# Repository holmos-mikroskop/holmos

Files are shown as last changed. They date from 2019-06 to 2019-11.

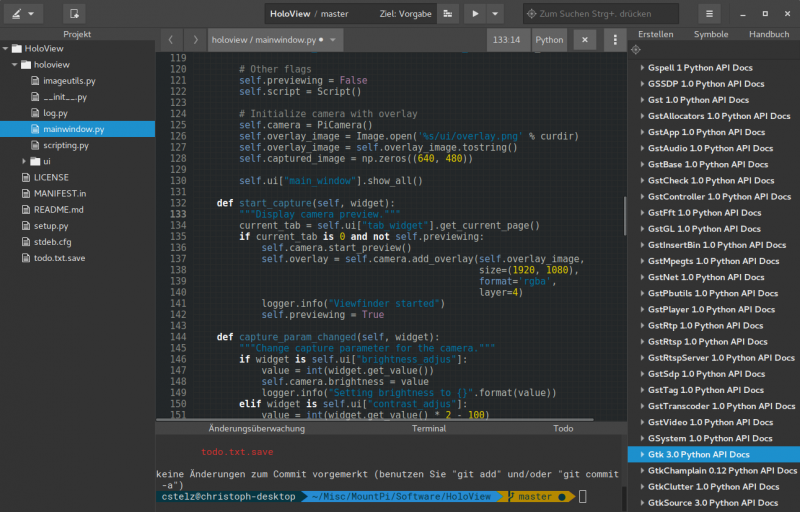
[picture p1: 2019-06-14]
doku-img/gnome-builder.png

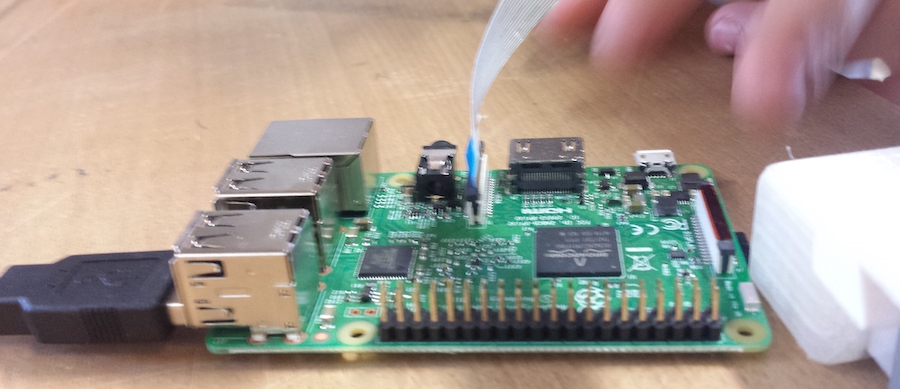
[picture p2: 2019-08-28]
doku-img/kamera-anschliessen-03.jpg

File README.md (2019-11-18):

# Digital-holographisches Mikroskop for OpenScience (HolMOS)

In diesem Projekt wurde von 2016 bis 2019 in Kooperation von Schüler/innen, Lehrern und Mitarbeitern des Fraunhofer-Instituts für Physikalische Messtechnik IPM ein **digital-holographisches Mikroskop entwickelt**, das für Schulen, andere Bildungseinrichtungen und alle Interessierten erschwinglich ist. Die Komponenten sind entweder günstig zu kaufen oder per 3D-Druck herstellbar und können selbst mit Hilfe von Anleitungen zusammen gebaut werden. 

Das Mikroskop ermöglicht 3D-Darstellungen von Objekten, die mit Hilfe des klassischen Lichtmikroskops weniger gut erforschbar sind. 

----

## Kooperationspartner

Das Projekt HolMOS wurde in Kooperation des 
* [Freiburg-Seminars für Mathematik und Naturwissenschaften](https://freiburg-seminar.de/stichwort/holmos/) mit dem     
* [Fraunhofer-Institut für Physikalische Messtechnik IPM](https://www.ipm.fraunhofer.de) in Freiburg durchgeführt. 
    
Gefördert durch das [BMBF](https://www.bmbf.de/).

----

##  Projektdokumentation und Status

Für die Projektdokumentation gibt es zwei parallele Strukturen: 

### (1) Erarbeitet von Schüler/innen

**Umfassende** Darstellung der entwickelten Inhalte und des Codes mit **Anleitungen auf Deutsch**. 

> **STATUS:** 
> * Die Dokumentation ist **abgeschlossen**, 
> * der Code und die Materialien werden **nicht mehr weiterentwickelt**. 

**[Zur Schüler-Dokumentation](https://github.com/holmos-mikroskop/holmos/wiki)**

### (2) Erarbeitet von Mitarbeitern des Fraunhofer IPM

**Knappe** Darstellung der entwickelten Inhalte und des Codes, **Anleitungen auf Englisch**.

> **STATUS:** 
> * Die Dokumentation ist noch **in Bearbeitung**, 
> * Code und Materialien **werden noch weiterentwickelt**. 

**[Zur Fraunhofer-Dokumentation](https://github.com/holmos-ipm)**

----

## Weitere Berichte zum Projekverlauf

Pressemeldungen und Berichte zu Meilensteinen des Projekts sind hier dokumentiert (in umgekehrt chronologischer Reihenfolge): [Projektdokumentation](https://freiburg-seminar.de/stichwort/holmos/)

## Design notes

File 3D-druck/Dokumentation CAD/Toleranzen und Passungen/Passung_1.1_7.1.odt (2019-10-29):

Passungen und Toleranzen

Maßtoleranzen sind die bei der Fertigung zulässigen Differenzen zum idealen Nennmaß. Beispielsweise ist das Ideale Nennmas bei einem Zollstoch 2m und die Maßtolerant beträgt +/- 0.2mm.

Wir benutzen Passungen und Toleranzen um Bauteile beweglich zu machen, da diese individuell einstellbar sein müssen. Wenn wir keine Passungen und Toleranzen benutzen würden, könnte man die Bauteile schwer oder gar nicht bewegen und dadurch kein gutes Bild erzielen.

1.1 / 7.1

Die folgende Passung wurde gewählt, dass die Bauteile perfekt ineinander passen, beweglich und trotzdem stabil sind. Die Bohrung an der Seite des Fußes wurden nicht mit einem Gewinde versehen, da wir M3 Schrauben benutzen, welche das Gewinde selber schneiden. Dies wird bei jedem weiteren Bauteil auch so gemacht.

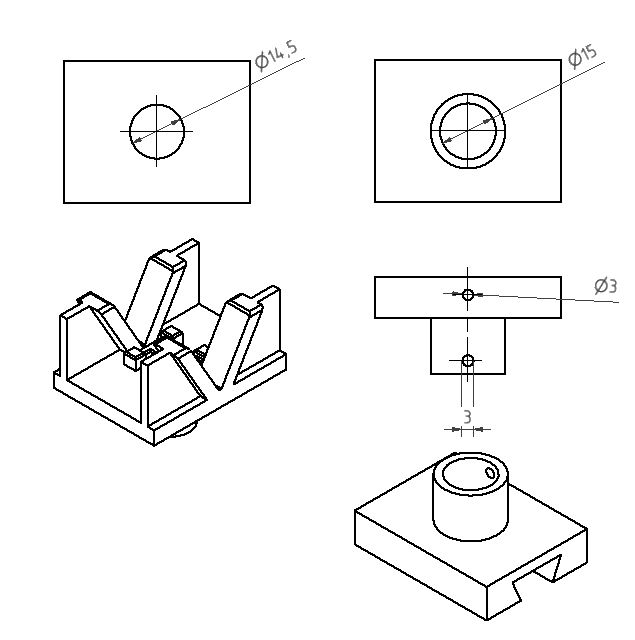
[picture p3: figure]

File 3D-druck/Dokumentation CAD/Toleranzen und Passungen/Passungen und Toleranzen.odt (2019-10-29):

Passungen und Toleranzen

7.1

Die Passungen wurden so Konstruiert das auf jeder Seite ein Millimeter spiel gelassen wurde. Siehe zeichnung.

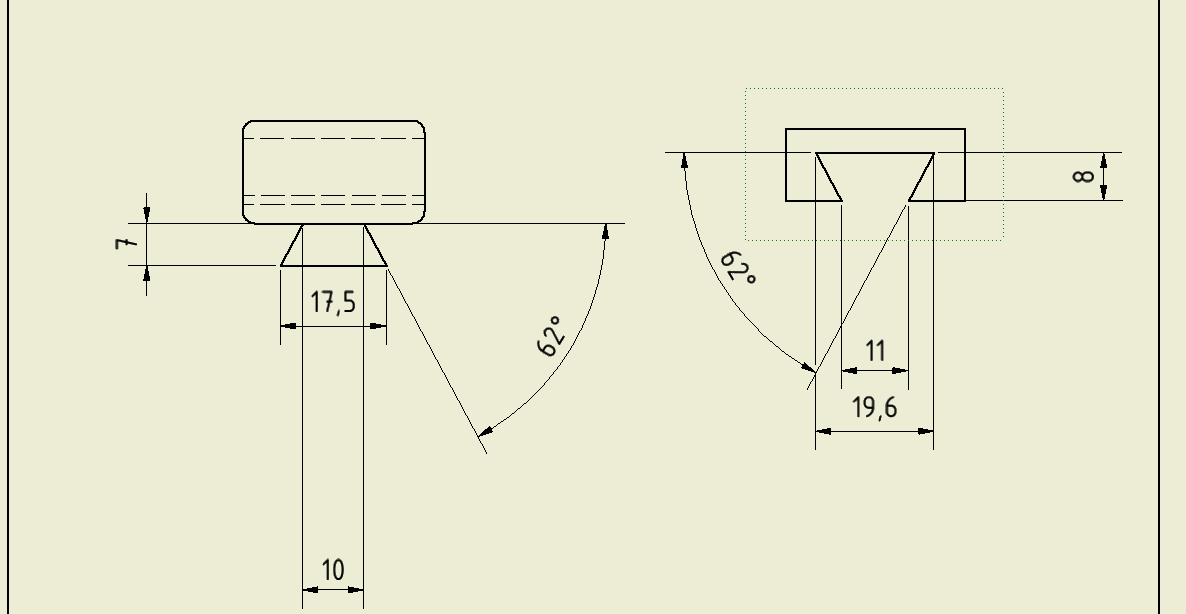
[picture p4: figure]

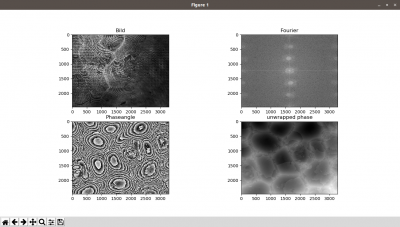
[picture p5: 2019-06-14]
doku-img/einfache-auswertung_004.png

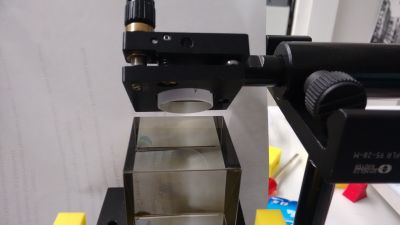
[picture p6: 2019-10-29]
doku-img/justage-laserpointer/justage-05.jpg

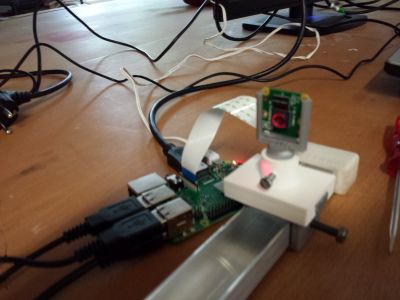
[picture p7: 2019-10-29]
doku-img/justage-laserdiode/justage-laserdiode-10.jpg

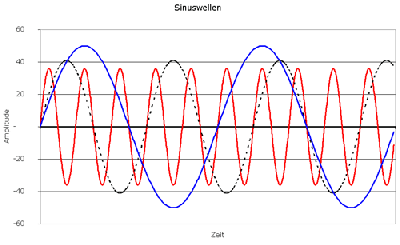
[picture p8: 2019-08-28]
doku-img/interferometer-005.gif

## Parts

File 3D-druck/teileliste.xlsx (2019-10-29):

Normteile | Größe | Länge | Kopf | Menge
1 | M5 | 20 mm | Flügelschraube | 6x | Grundkonstruktion
2 | M3 | 20 mm | Flügelschraube | 5x
3 | M3 | 7 mm | Innensechskant | 4x
4 | M3 | 35 / 40 mm | Innensechskant | 2x | Objektivhalter
5 | M3 |  | Muttern | 2x
6 | M3 | 20 mm | Innensechskant | 4x | Strahlenteiler
7 | M3 |  | Muttern | 4x
8 | M3 | 10 mm | Innensechskant | 4x
9 |  |  | Schiene | 1x
10 |  |  | Kugelschreiberfeder | 4x
11 | Durchmesser 6mm | Gesamtlänge ca. 250mm (6x30mm) | Aluminiumstange | 1x
12 | M5 | 20 mm | Innensechskant | 3x
13 | M5 |  | Muttern | 3x
Druckteile | Pos. Nr. | Name | Menge
 | 1.1 | Laserhalter | 1x | Laser
 | 2.1 | Linse | 1x | Linse
 | 3.1 | Strahlenteiler | 1x | Strahlenteiler
 | 3.2 | Strahlenteiler | 1x | Strahlenteiler
 | 3.3 | Strahlenteiler | 2x | Strahlenteiler
 | 3.4 | Strahlenteiler | 1x | Strahlenteiler
 | 4.1 | Objektträgerhalterung | 1x | Objektträgerhalterung
 | 4.2a | Objektträgerhalterung | 1x | Objektträgerhalterung
 | 4.2b | Objektträgerhalterung | 1x | Objektträgerhalterung
 | 5.1 | Objektivhalterung | 1x | Objektivhalterung
 | 5.2 | Objektivhalterung | 1x | Objektivhalterung
 | 6.1 | Kamera | 1x | Kamera
 | 7.1 | Schlitten mit Rundung verschoben | 3x
 | 7.1 | Schlitten mit Rundung verschoben | 1x
 | 7.1 | Schlitten | 1x
 | 7.2 | Schienenläufer | 5x
 | 7.3 | Schienenläufer STL | 1x
 | 7.4 | Schienenschutz | 2x | Schienenschutz
Optische Komponenten | Name | Beschreibung | Menge | Link
 | Lasermodul: | Laserfuchs Diode OE-QD650-0.4-12(10x22)-ADJ, |  | https://www.laserfuchs.de/de/punktlaser/doe-qd650-0-4-1210x22-adj, Fokus
 | Strahlteiler | 15x15x1mm |  | https://www.lasershop.de/de/strahlteiler-laser-50-50-strahlteilerspiegel.html
 | Spiegel: | Vorderflächen-Glasspiegel 50 mm x 40 mm x 1,3mm |  | https://www.forscherladen.de/vorderflaechen-glasspiegel-50-mm-x-40-mm-x-1-3mm::10-509.VFX.html
 | Linse | Astromedia om-3, plankonvex, +30mm, Durchmesser 16,5mm |  | https://www.forscherladen.de/opti-media-linse-nr.3-brennweite-30-mm::10-304.OML.html

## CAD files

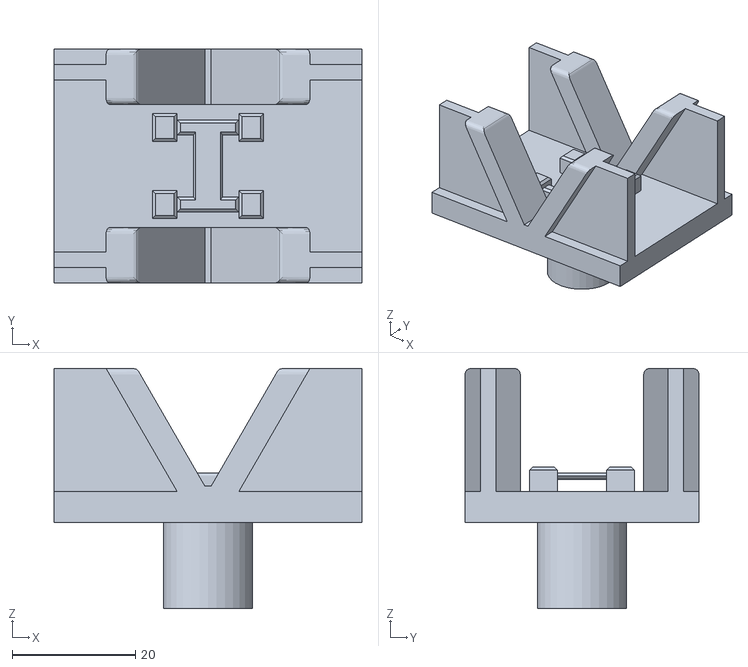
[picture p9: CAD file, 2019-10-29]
3D-druck/1 Laserhalter/1 Laserhalterung/1.1 Laserhalter Oberteil 29112018.stl
50.0 x 38.0 x 39.0

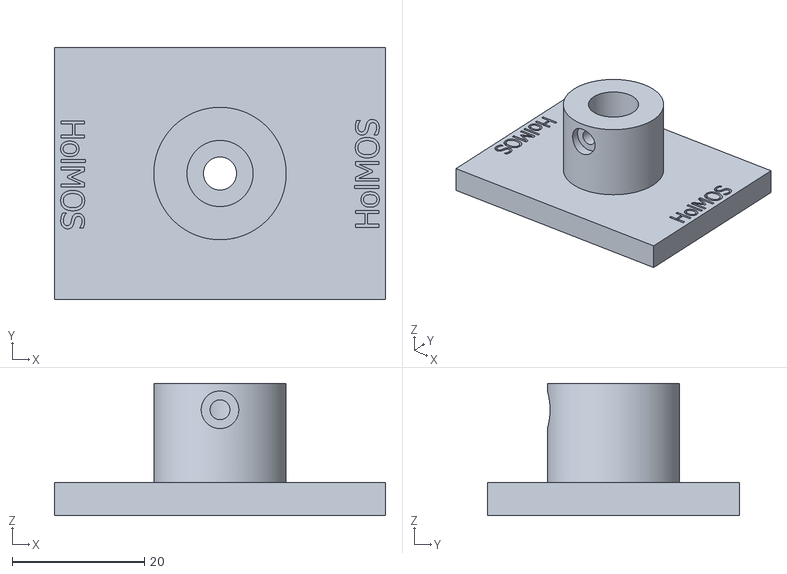
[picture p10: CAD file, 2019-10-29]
3D-druck/1 Laserhalter/1 Laserhalterung/Mit Schrift/1.3 Laserhalter_unten.stl
50.0 x 38.0 x 20.0

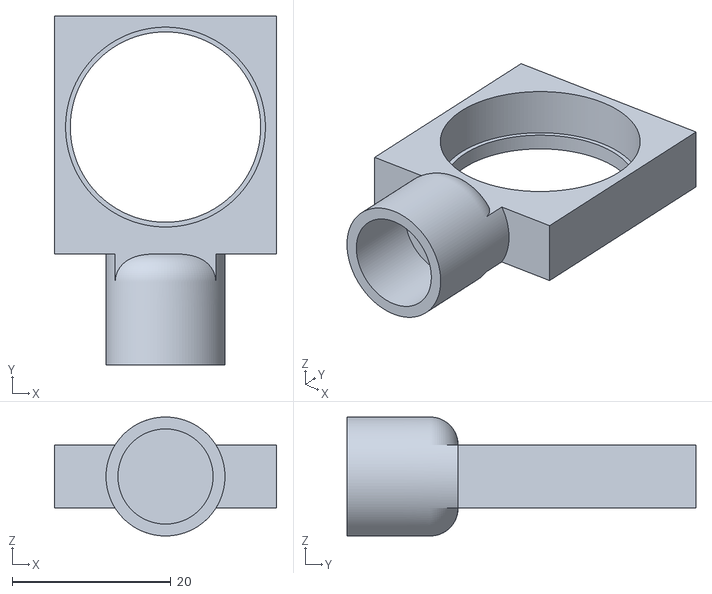
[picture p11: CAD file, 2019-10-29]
3D-druck/2 Linsenhalterung/2.1 Linsenhalter 25,2.stl
28.0 x 44.0 x 15.0

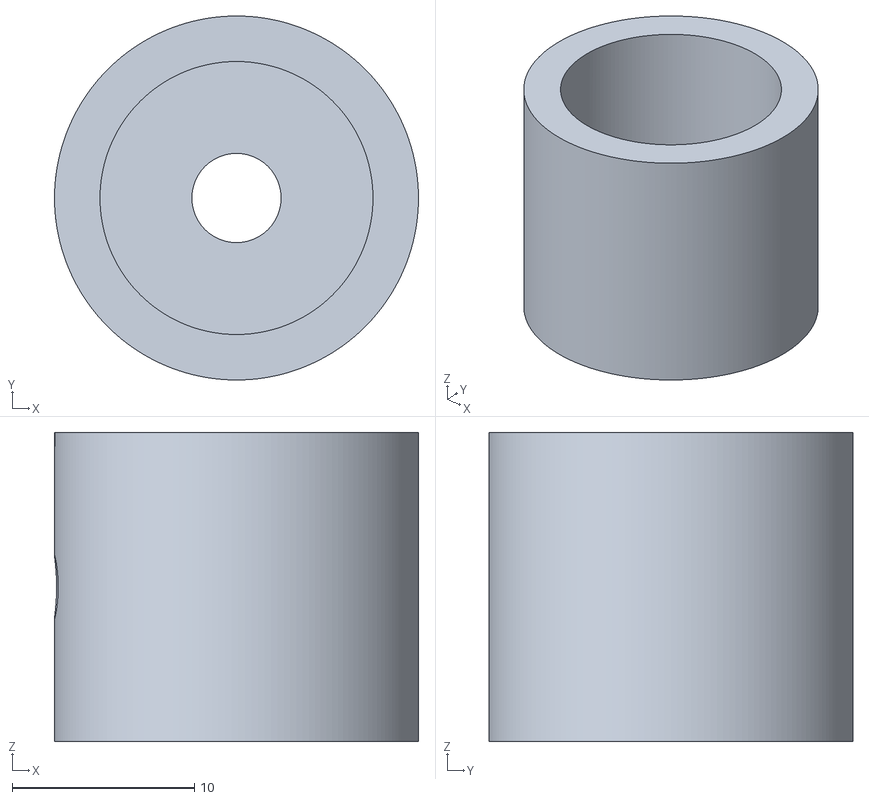
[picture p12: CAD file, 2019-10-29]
3D-druck/2 Linsenhalterung/Mit Schrift/2.2 Fuß.stl
20.0 x 20.0 x 17.0

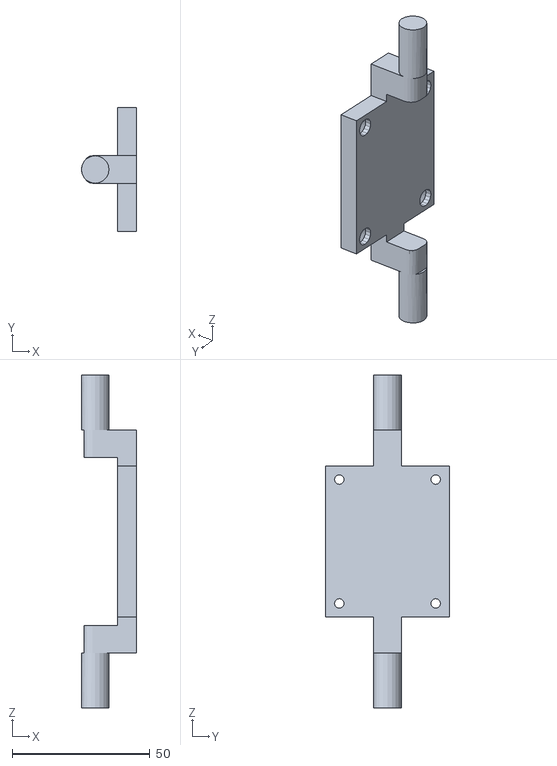
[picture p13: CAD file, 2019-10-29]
3D-druck/3 Strahlenteiler/3.4 Spieghalter 2.0.stl
20.0 x 45.0 x 121.0

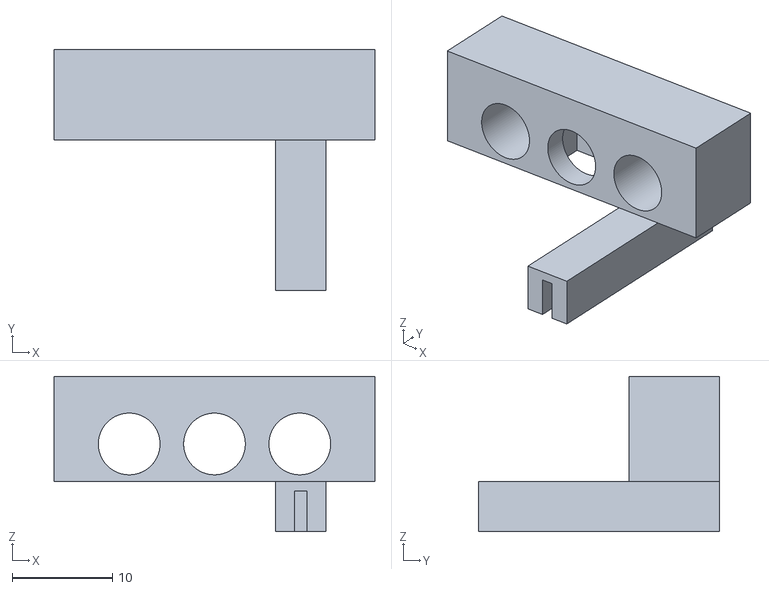
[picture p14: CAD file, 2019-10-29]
3D-druck/4 Objekthalterung/alle alte dateien/Objektträgerhalter 3a Neu.stl
32.0 x 24.0 x 15.5

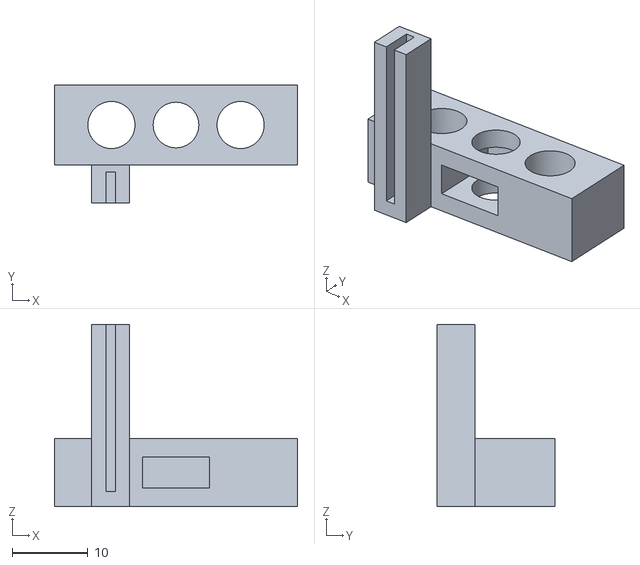
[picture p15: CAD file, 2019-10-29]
3D-druck/4 Objekthalterung/Finale Dateien/Objektträgerhalter 2b.stl
32.0 x 15.5 x 24.0

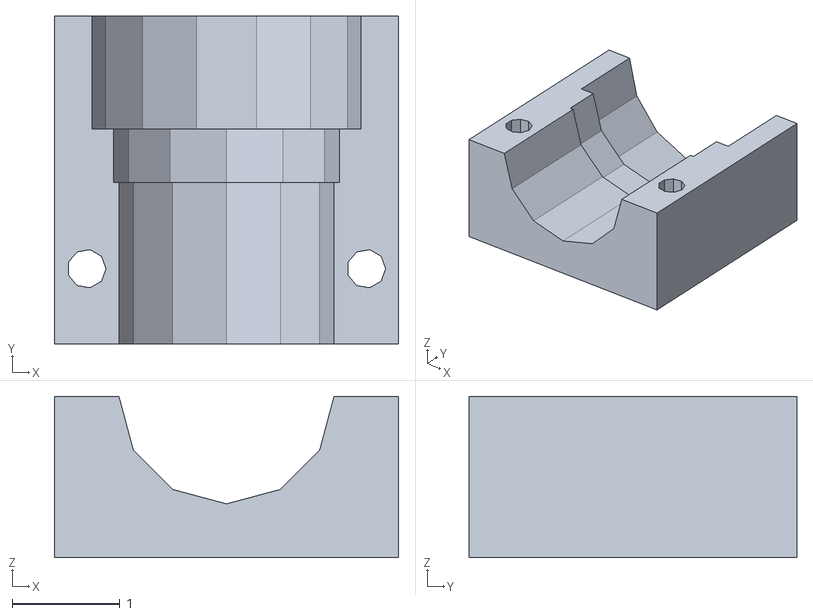
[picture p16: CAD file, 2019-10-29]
3D-druck/5 Objektivhalterung/5 Objektivhalterung/5.2 Objektivhalterung oben 29112018.stl
3.20 x 3.05 x 1.50

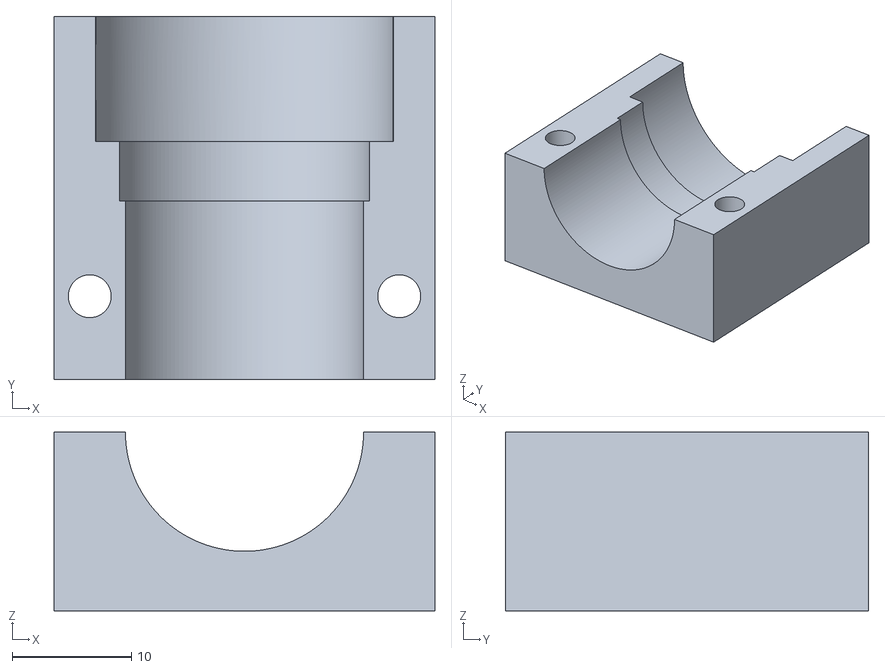
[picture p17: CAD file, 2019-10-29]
3D-druck/5 Objektivhalterung/5 Objektivhalterung/Mit Schrift/5.2 Objektivhalterung_Oben.stl
32.0 x 30.5 x 15.0

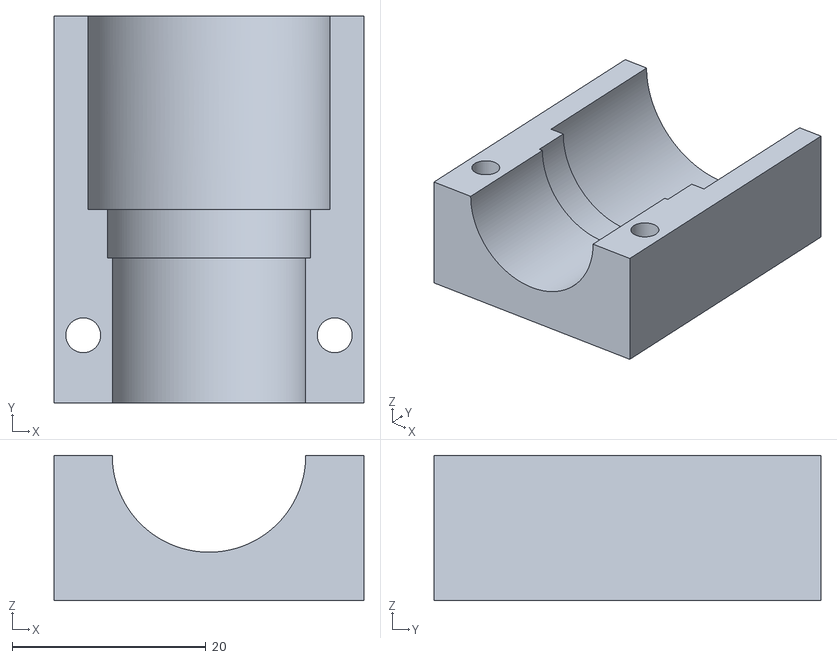
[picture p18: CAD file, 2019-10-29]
3D-druck/5 Objektivhalterung/oberteil.stl
32.0 x 40.0 x 15.0

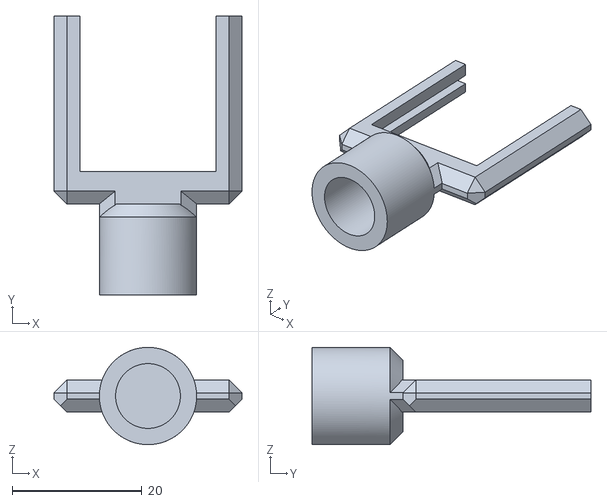
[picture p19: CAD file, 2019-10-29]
3D-druck/6 Kamerahalterung/6 Kamerahalterung.stl
29.0 x 43.0 x 15.0

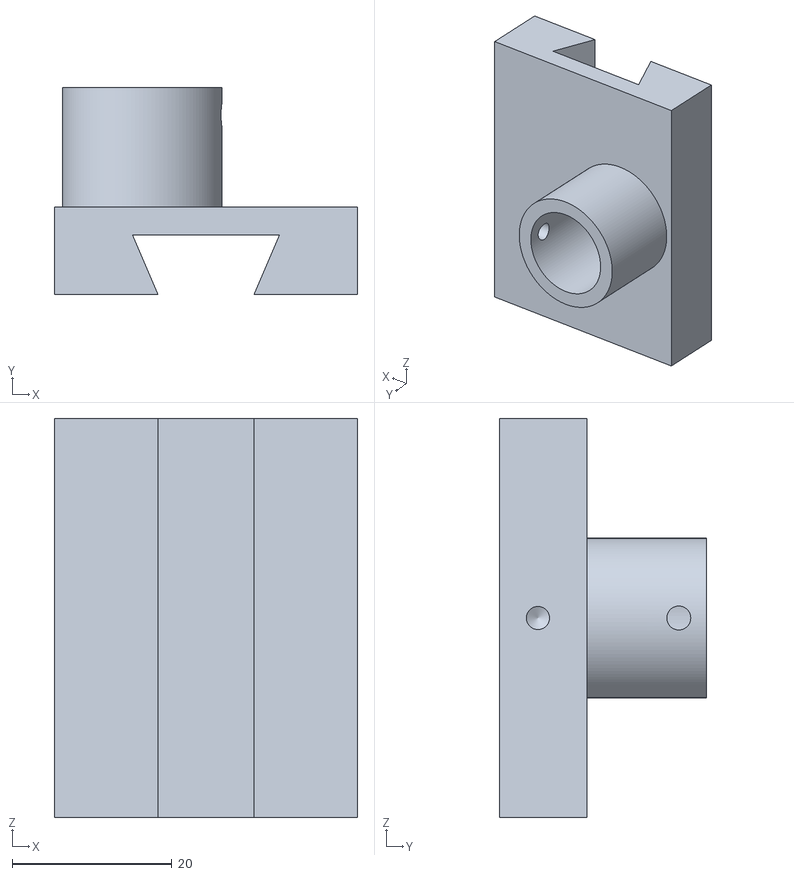
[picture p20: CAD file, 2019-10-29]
3D-druck/7 Grundkonstruktion/7.1 Schlitten mit Rundung für Objektivhalter.stl
38.0 x 26.0 x 50.0

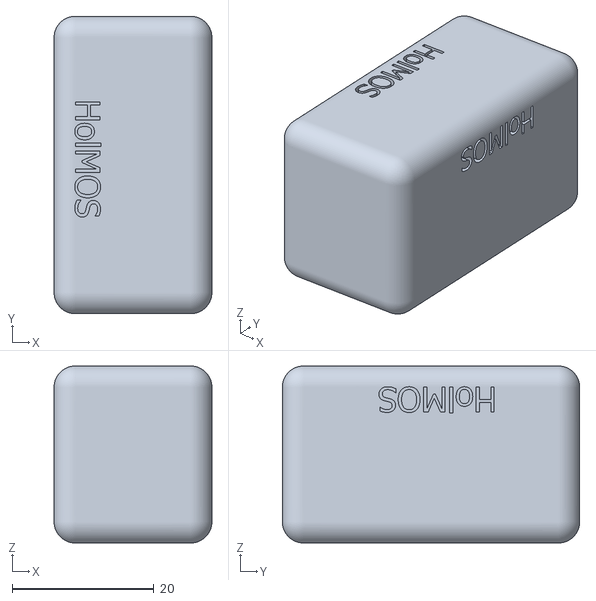
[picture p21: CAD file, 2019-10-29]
3D-druck/7 Grundkonstruktion/Mit Schrift/7.3 Schienendteil.stl
22.3 x 42.0 x 25.0

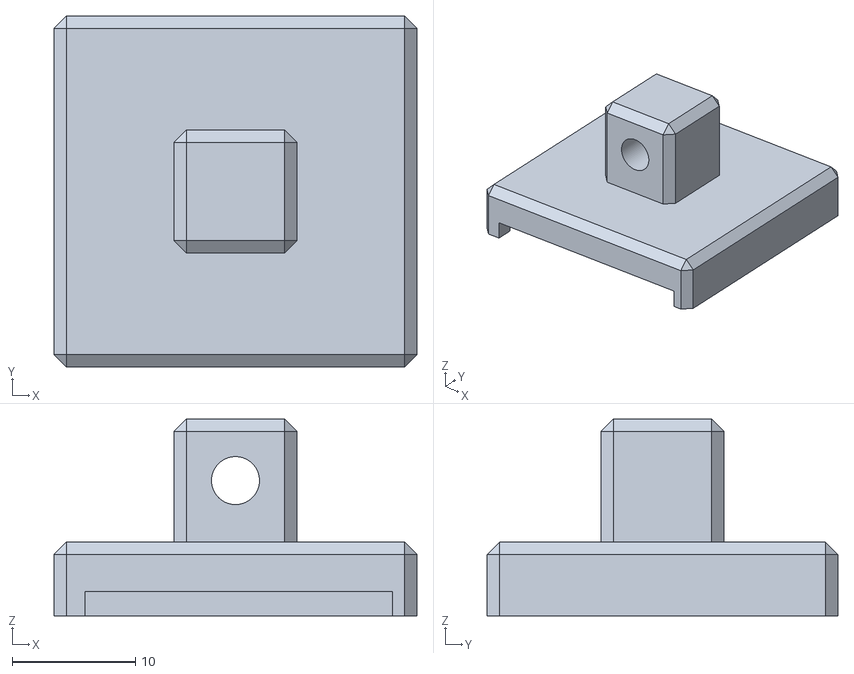
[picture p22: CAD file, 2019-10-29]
3D-druck/Kamerahalter 03.5/Raspberrycamhalter.stl
29.5 x 28.5 x 16.0

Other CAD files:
3D-druck/6 Kamerahalterung/Mit Schrift/6.1 Kamerahaltung.stl
3D-druck/Dokumentation CAD/Toleranzen und Passungen/1.1 Laserhalter_Oben.dwg
3D-druck/Objektträgerhalter stl/Objektträgerhalter 3a.stl
3D-druck/Schiene_27.5_Neu/3d-Druck_Fertig/Schienenläufer_mit_keil_27.5_15.11.stl
3D-druck/1 Laserhalter/1 Laserhalterung/1.0 Laserhalterung.iam
3D-druck/1 Laserhalter/1 Laserhalterung/1.1 Laserhalter Oberteil 20190411.2 x1.stl
3D-druck/1 Laserhalter/1 Laserhalterung/1.1 Laserhalter Oberteil 20190411.2.ipt
3D-druck/1 Laserhalter/1 Laserhalterung/1.1 Laserhalter Oberteil 20190411.ipt
3D-druck/1 Laserhalter/1 Laserhalterung/1.1 Laserhalter Oberteil 20190411.stl
3D-druck/1 Laserhalter/1 Laserhalterung/1.1 Laserhalter Oberteil 29112018.ipt
3D-druck/1 Laserhalter/1 Laserhalterung/1.2 Laserhalter Mittelteil 29112018.ipt
3D-druck/1 Laserhalter/1 Laserhalterung/1.2 Laserhalter Mittelteil 29112018.stl
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

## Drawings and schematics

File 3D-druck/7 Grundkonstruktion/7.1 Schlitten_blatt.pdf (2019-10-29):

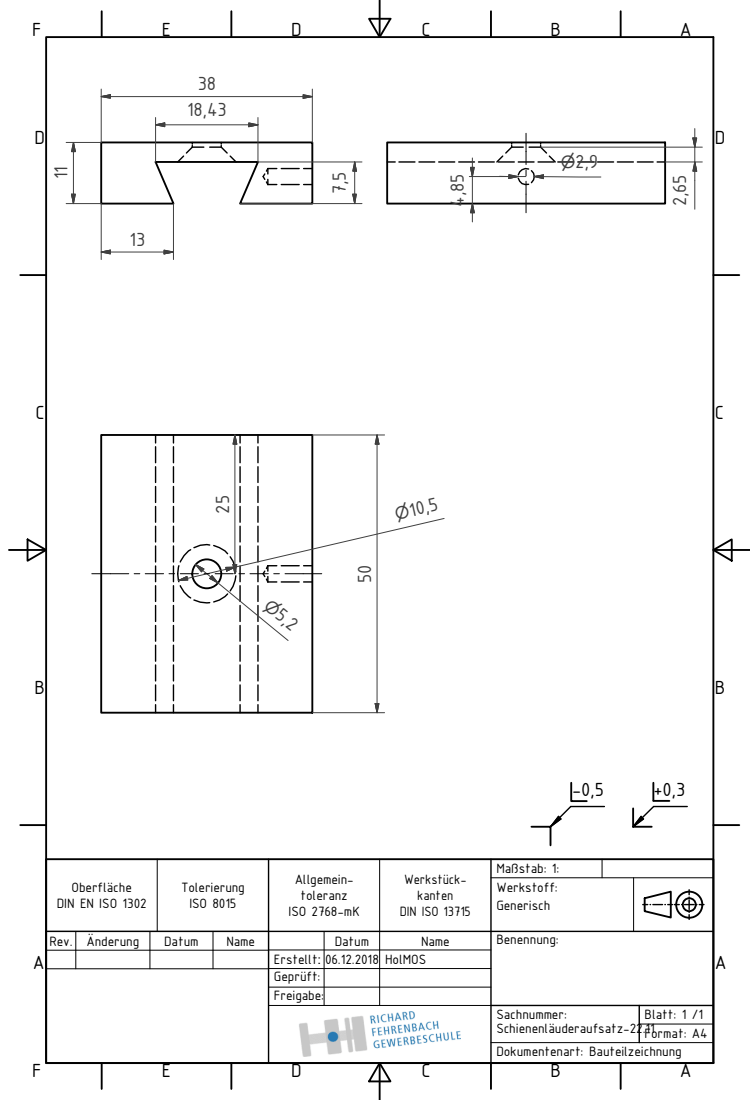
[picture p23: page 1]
Format: A4 Dokumentenart: Bauteilzeichnung

Oberflche DIN EN ISO 1302 | Tolerierung ISO 8015 | Allgemein-toleranz ISO 2768-mK | Werkst¯ck-kanten DIN ISO 13715 | Mastab: 1:
Werkstoff: Generisch

Rev. | |nderung | Datum | Name | | Datum | Name | Benennung:

Erstellt: | 06.12.2018 | HolMOS
Gepr¯ft:
Freigabe:

Sachnummer: Schienenluderaufsatz-22.11 | Blatt: 1 /1

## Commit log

2019-10-29 Upload der 3D-Druck Dateien
    [1.0 Laserhalterung.iam, 1.1 Laserhalter Oberteil 20190411.2 x1.stl, 1.1 Laserhalter Oberteil 20190411.2.ipt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]
2019-10-29 Abb. der Dokumentation in Unterordner verschoben
2019-10-29 Abb. Laserpointer-Justage ergänzt
2019-10-29 Abb. zur Laserpointerjustage ergänzt
2019-10-29 Abb. Justage mit Laserdiode ergänzt
2019-10-30 Größere Version des Fotos
2019-10-30 Änderung der Abb.
